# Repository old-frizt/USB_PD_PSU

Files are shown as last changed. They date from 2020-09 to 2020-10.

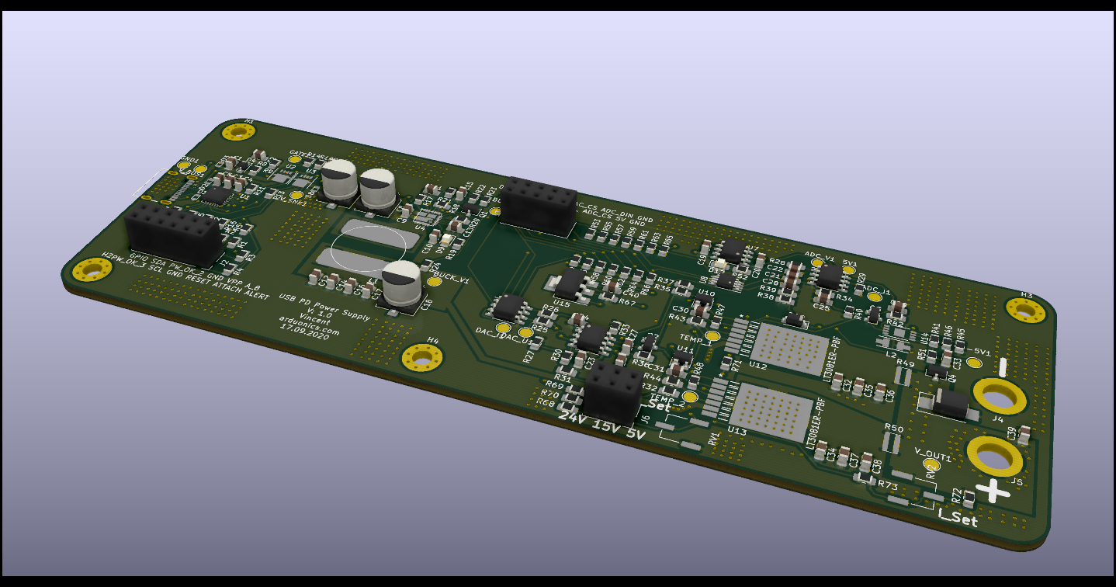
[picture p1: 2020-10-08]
USB_PD_PSU_render.png

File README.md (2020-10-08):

# USB_PD_PSU
DIY USB Power Delivery Lab Bench Power Supply

WORK-IN-PROGRESS

This is a power supply with a linear ouput stage and a switching pre regulator.
In the future it will be controlled via a microcontroller doughter board.

The power to the supply is comes from USB Power-delivery at 20V.
The ouput can be set between 0-20V and 0-3A.

Additional information can be found on my website: https://arduonics.com/2020/electronics/diy-usb-power-delivery-lab-bench-power-supply/

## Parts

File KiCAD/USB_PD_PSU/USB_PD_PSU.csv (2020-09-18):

Source: | E:\DOKUMENTE\KiCAD\PSU\psu\USB_PD_PSU\USB_PD_PSU.sch
Date: | 15.09.2020 12:40:33
Tool: | Eeschema (5.1.6)-1
Generator: | C:\Program Files\KiCad\bin\scripting\plugins/bom_csv_grouped_by_value_with_fp_DigiKey.py
Component Count: | 132
Ref | Qnty | Value | Cmp name | Footprint | DigiKey
C1, | 1 | C CER 4.7uF 20V X5R | C | Capacitor_SMD:C_0805_2012Metric_Pad1.15x1.40mm_HandSolder
C2, C3, C4, C5, C13, C24, C30, C31, C39, | 9 | 1uF | C | Capacitor_SMD:C_0805_2012Metric_Pad1.15x1.40mm_HandSolder
C6, C9, C19, C20, C21, C22, C25, | 7 | 100nF | C | Capacitor_SMD:C_0805_2012Metric_Pad1.15x1.40mm_HandSolder
C7, C8, | 2 | 22uF | C | Capacitor_SMD:C_0805_2012Metric_Pad1.15x1.40mm_HandSolder
C10, | 1 | 4u7F | C | Capacitor_SMD:C_0805_2012Metric_Pad1.15x1.40mm_HandSolder
C11, | 1 | 0.1uF | C | Capacitor_SMD:C_0805_2012Metric_Pad1.15x1.40mm_HandSolder
C12, C14, C16, C17, | 4 | 4u7 | C | Capacitor_SMD:C_0805_2012Metric_Pad1.15x1.40mm_HandSolder
C15, C23, C26, C27, | 4 | 1nF | C | Capacitor_SMD:C_0805_2012Metric_Pad1.15x1.40mm_HandSolder
C18, C28, | 2 | 100uF | C | Capacitor_SMD:C_0805_2012Metric_Pad1.15x1.40mm_HandSolder
C29, C32, C33, C34, C35, C36, C37, C38, | 8 | 10uF | C | Capacitor_SMD:C_0805_2012Metric_Pad1.15x1.40mm_HandSolder
D1, D2, D3, D8, | 4 | ESDA25P35 | D_Zener | Diode_SMD:QFN_1610_2-UDFN_ESDA25P35 | 497-16913-1-ND‎
D4, | 1 | D_Schottky | D_Schottky | Diode_SMD:D_SOD-323_HandSoldering | BAT54HT1GOSCT-ND
D5, D6, D7, D9, | 4 | LED | LED | LED_SMD:LED_0805_2012Metric_Pad1.15x1.40mm_HandSolder | 732-4987-1-ND
D10, | 1 | MBR0540 | MBR0540 | Diode_SMD:D_SOD-123 | MBR0540T3GOSCT-ND
D11, | 1 | SM6T36A | D | Diode_SMD:D_SMB_Handsoldering | ‎497-6495-1-ND‎
J1, | 1 | USB_C_Receptacle_UJ31-CH-3-SMT-TR | USB_C_Receptacle_UJ31-CH-3-SMT-TR | Connector_USB:CUI_UJ31-CH-3-SMT-TR | 102-4484-1-ND
J2, | 1 | Conn_02x06_Counter_Clockwise | Conn_02x06_Counter_Clockwise | Connector_PinSocket_2.54mm:PinSocket_2x06_P2.54mm_Vertical
L1, | 1 | SDR1307-5R6ML | L | USB_PD_PSU:Inductor_SDR1307 | SDR1307-5R6MLCT-ND
L2, | 1 | 470u_LQH32CN471K23L | L | USB_PD_PSU:LQH32CN471K23L | 490-2499-1-ND
Q1, Q3, | 2 | MMBT3906 | MMBT3906 | Package_TO_SOT_SMD:SOT-23 | MMBT3906-FDICT-ND
Q2, | 1 | BC846BLT1G | BC847 | Package_TO_SOT_SMD:SOT-23 | BC846BLT1GOSCT-ND
Q4, | 1 | FMMT493TA | Q_NPN_BEC | Package_TO_SOT_SMD:SOT-23 | FMMT493CT-ND
R1, R6, R7, | 3 | 4k7 | R | Resistor_SMD:R_0805_2012Metric_Pad1.15x1.40mm_HandSolder
R2, R3, R4, R5, R10, R23, R24, | 7 | 100k | R | Resistor_SMD:R_0805_2012Metric_Pad1.15x1.40mm_HandSolder
R8, | 1 | 470 | R | Resistor_SMD:R_0805_2012Metric_Pad1.15x1.40mm_HandSolder
R9, R12, R13, R15, R16, R19, R22, R36, R40, | 9 | 1k | R | Resistor_SMD:R_0805_2012Metric_Pad1.15x1.40mm_HandSolder
R11, | 1 | 22k | R | Resistor_SMD:R_0805_2012Metric_Pad1.15x1.40mm_HandSolder
R14, R28, R29, | 3 | 100 | R | Resistor_SMD:R_0805_2012Metric_Pad1.15x1.40mm_HandSolder
R17, | 1 | 2.2 | R | Resistor_SMD:R_0805_2012Metric_Pad1.15x1.40mm_HandSolder
R18, | 1 | 51k | R | Resistor_SMD:R_0805_2012Metric_Pad1.15x1.40mm_HandSolder
R20, R35, R37, | 3 | 4k99 | R | Resistor_SMD:R_0805_2012Metric_Pad1.15x1.40mm_HandSolder
R21, | 1 | 499k | R | Resistor_SMD:R_0805_2012Metric_Pad1.15x1.40mm_HandSolder
R25, R26, | 2 | 33k2 | R | Resistor_SMD:R_0805_2012Metric_Pad1.15x1.40mm_HandSolder
R27, | 1 | 4k4 | R | Resistor_SMD:R_0805_2012Metric_Pad1.15x1.40mm_HandSolder
R30, | 1 | 11k | R | Resistor_SMD:R_0805_2012Metric_Pad1.15x1.40mm_HandSolder
R31, | 1 | 50k | R | Resistor_SMD:R_0805_2012Metric_Pad1.15x1.40mm_HandSolder
R32, | 1 | 10 | R | Resistor_SMD:R_0805_2012Metric_Pad1.15x1.40mm_HandSolder
R33, | 1 | 41k | R | Resistor_SMD:R_0805_2012Metric_Pad1.15x1.40mm_HandSolder
R34, | 1 | 5k | R | Resistor_SMD:R_0805_2012Metric_Pad1.15x1.40mm_HandSolder
R38, | 1 | 300k | R | Resistor_SMD:R_0805_2012Metric_Pad1.15x1.40mm_HandSolder
R39, | 1 | 99k | R | Resistor_SMD:R_0805_2012Metric_Pad1.15x1.40mm_HandSolder
R41, | 1 | 10k | R | Resistor_SMD:R_0805_2012Metric_Pad1.15x1.40mm_HandSolder
R42, | 1 | 806k | R | Resistor_SMD:R_0805_2012Metric_Pad1.15x1.40mm_HandSolder
R43, R44, R51, | 3 | 3k2 | R | Resistor_SMD:R_0805_2012Metric_Pad1.15x1.40mm_HandSolder
R45, | 1 | 1M47 | R | Resistor_SMD:R_0805_2012Metric_Pad1.15x1.40mm_HandSolder
R46, | 1 | 280k | R | Resistor_SMD:R_0805_2012Metric_Pad1.15x1.40mm_HandSolder
R47, R48, | 2 | 402 | R | Resistor_SMD:R_0805_2012Metric_Pad1.15x1.40mm_HandSolder
R49, R50, | 2 | 0.1/1W | R | Resistor_SMD:CFG0612 | LTC3632EMS8E#PBF-ND‎
TP1, | 1 | GND | TestPoint | TestPoint:TestPoint_Pad_D2.0mm
TP2, | 1 | CC1 | TestPoint | TestPoint:TestPoint_Pad_D2.0mm
TP3, | 1 | CC2 | TestPoint | TestPoint:TestPoint_Pad_D2.0mm
TP4, | 1 | VBUS | TestPoint | TestPoint:TestPoint_Pad_D2.0mm
TP5, TP6, | 2 | 2V7 | TestPoint | TestPoint:TestPoint_Pad_D2.0mm
TP7, | 1 | VDD | TestPoint | TestPoint:TestPoint_Pad_D2.0mm
TP8, | 1 | GATE | TestPoint | TestPoint:TestPoint_Pad_D2.0mm
TP9, | 1 | VSNK | TestPoint | TestPoint:TestPoint_Pad_D2.0mm
U1, | 1 | STUSB4500QTR | STUSB4500QTR | Package_DFN_QFN:QFN-24-1EP_4x4mm_P0.5mm_EP2.7x2.7mm | 497-18060-1-ND
U2, U3, | 2 | STL6P3LLH6 | STL6P3LLH6 | Package_DFN_QFN:8-PowerVDFN | 497-15315-1-ND
U4, | 1 | SIC438AED | SIC438AED | USB_PD_PSU:MLP44-24L PowerPAK | SIC438AED-T1-GE3CT-ND
U5, | 1 | MCP4822 | MCP4822 | Package_SO:SOIC-8_3.9x4.9mm_P1.27mm | MCP4822-E/SN-ND‎
U6, | 1 | MCP6422T-E/SN | Opamp_Dual_Generic | Package_SO:SOIC-8_3.9x4.9mm_P1.27mm | MCP6422T-E/SNCT-ND
U7, | 1 | L78L05_SO8 | L78L05_SO8 | Package_SO:SOIC-8_3.9x4.9mm_P1.27mm | ‎497-7267-1-ND‎
U8, | 1 | MCP3202 | MCP3202 | Package_SO:MSOP-8_3x3mm_P0.65mm | MCP3202T-CI/MSCT-ND
U9, | 1 | LT1013DDR | LT1013DDR | Package_SO:SOIC-8_3.9x4.9mm_P1.27mm | 296-14615-1-ND‎
U10, U11, | 2 | BCV62CE6327HTSA1 | BCV62CE6327HTSA1 | Package_TO_SOT_SMD:SOT-143 | ‎BCV62CE6327HTSA1CT-ND‎
U12, U13, | 2 | LT3081ER-PBF | LT3081ER-PBF | Package_DD:LT3081ER_7-DDPAK | ‎LT3081ER#PBF-ND‎
U14, | 1 | LTC3632 | LTC3632 | Package_SO:MSOP_MS8E | LTC3632EMS8E#PBF-ND‎

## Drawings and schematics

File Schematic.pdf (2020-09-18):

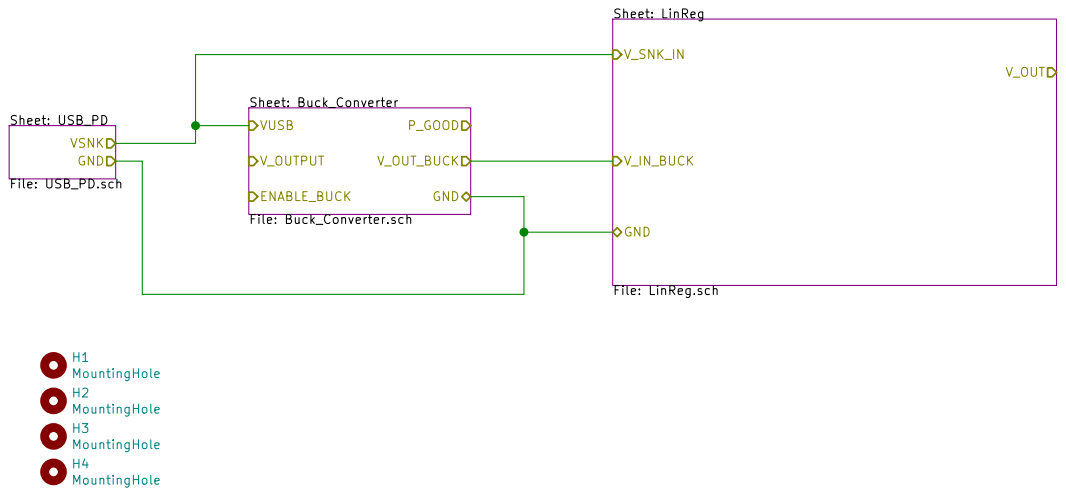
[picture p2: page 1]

Sheet: Buck_Converter File: Buck_Converter.sch VUSB

Sheet: USB_PD
File: USB_PD.sch VSNK GND

File: USB_PD_PSU.sch Sheet: / arduonics.com

Id: 1/4 Title: USB PD PSU

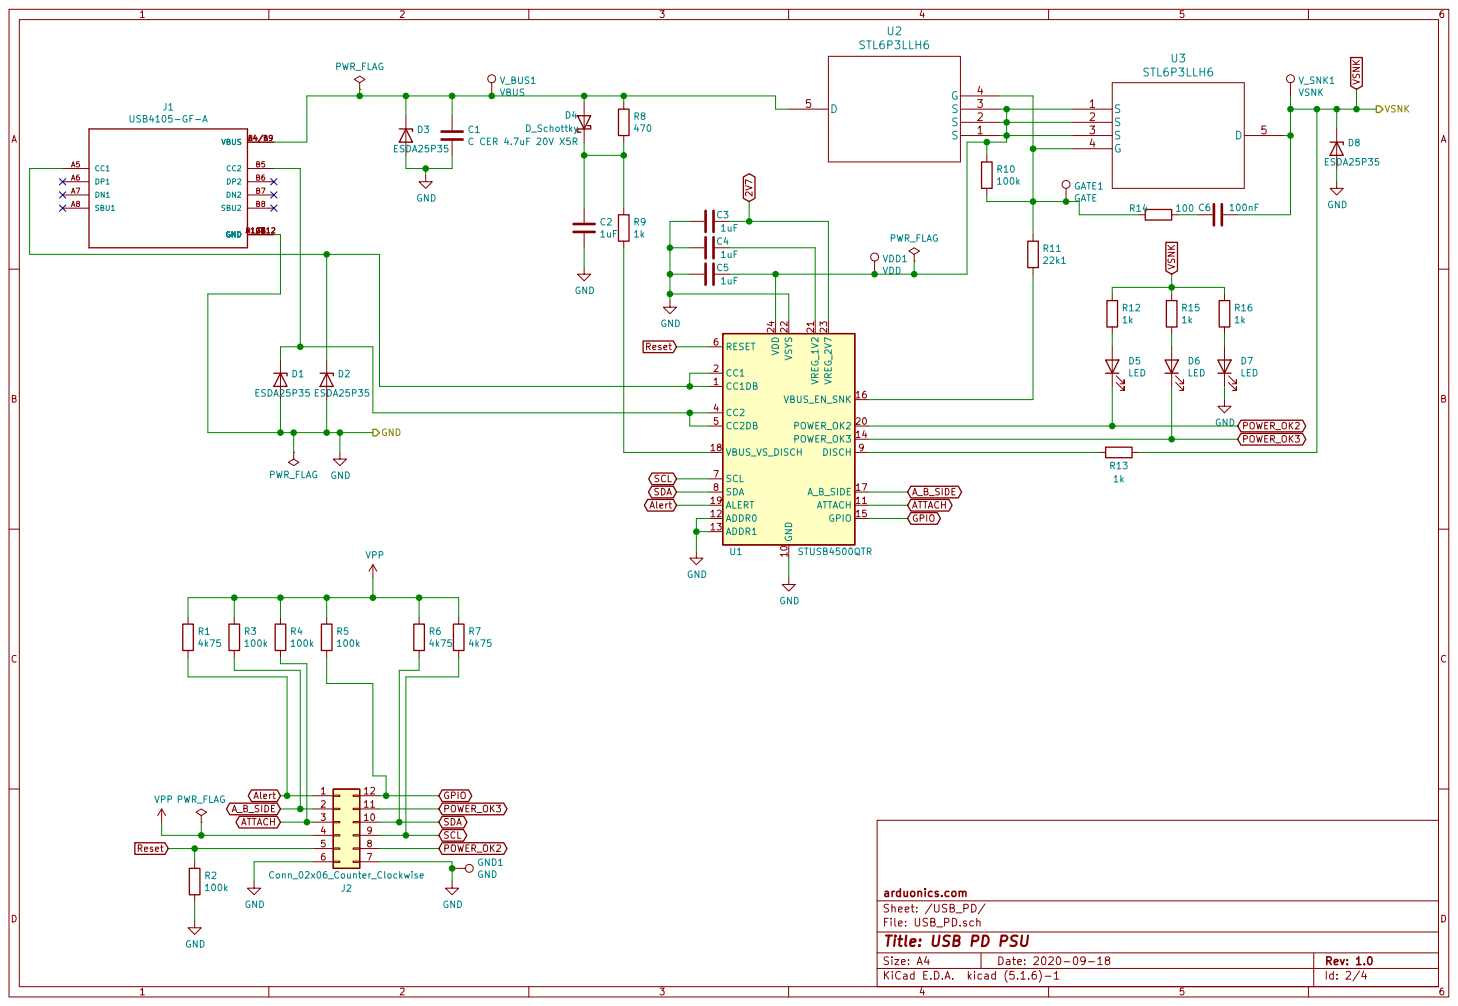
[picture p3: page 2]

File: USB_PD.sch
Id: 2/4 Title: USB PD PSU

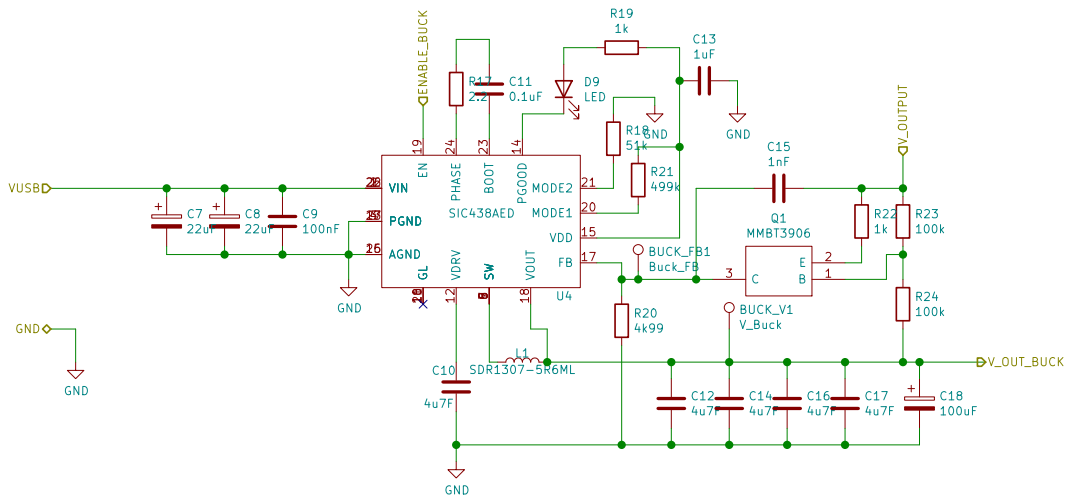
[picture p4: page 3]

File: Buck_Converter.sch
Id: 3/4 Title: USB PD PSU

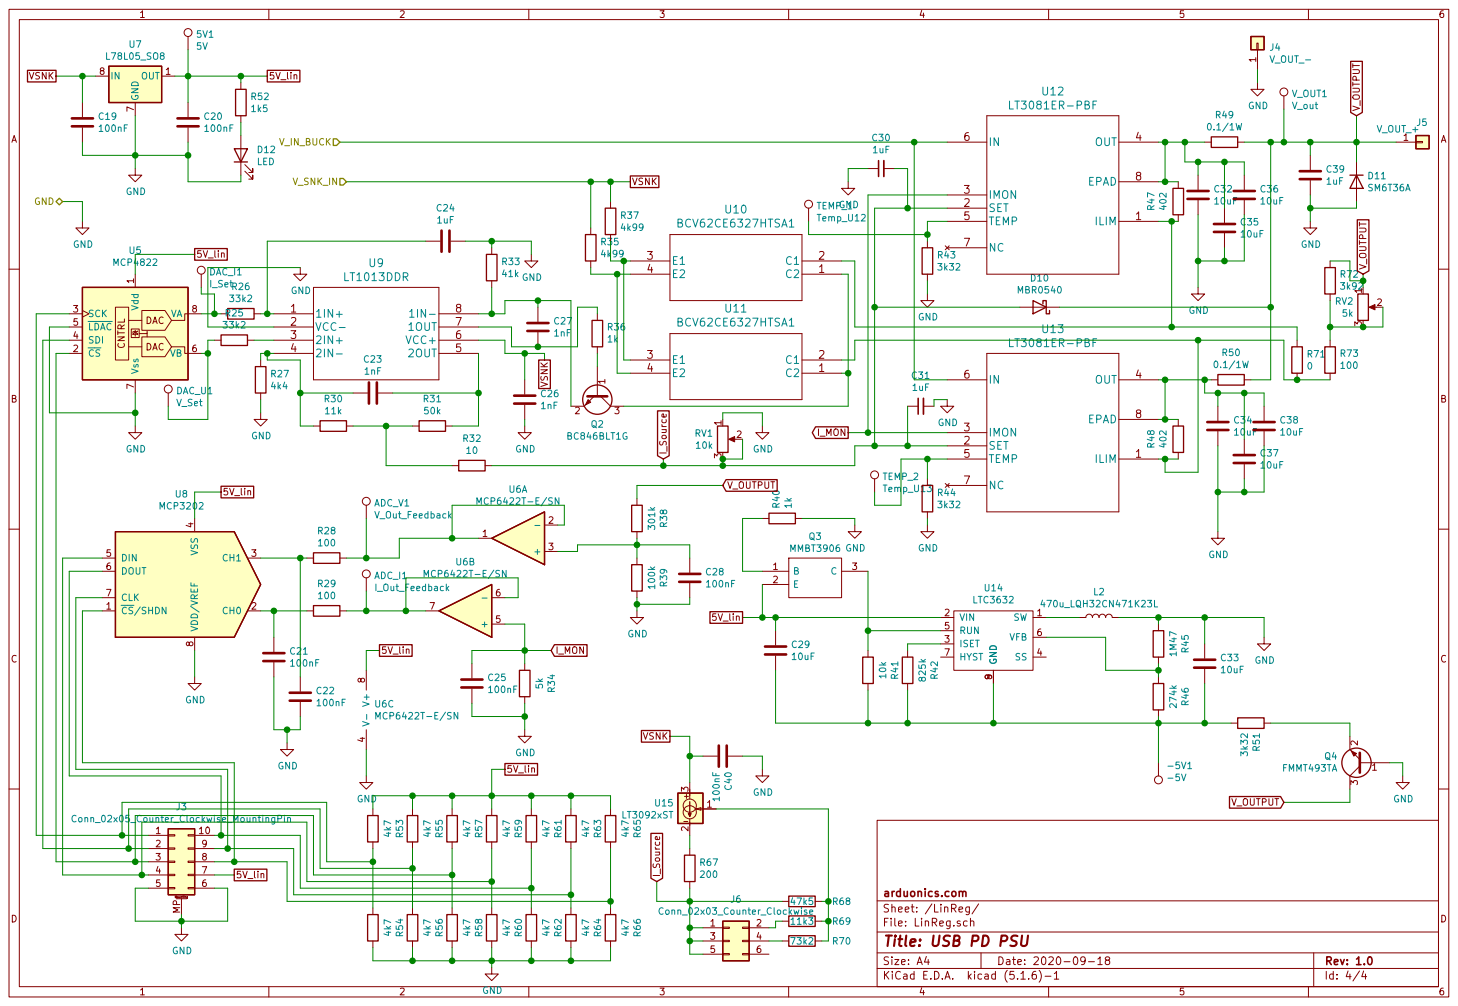
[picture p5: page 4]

4 DIN 5 DOUT 6 CLK 7 VDD/VREF

Sheet: /LinReg/ arduonics.com

File: LinReg.sch
Id: 4/4 Title: USB PD PSU

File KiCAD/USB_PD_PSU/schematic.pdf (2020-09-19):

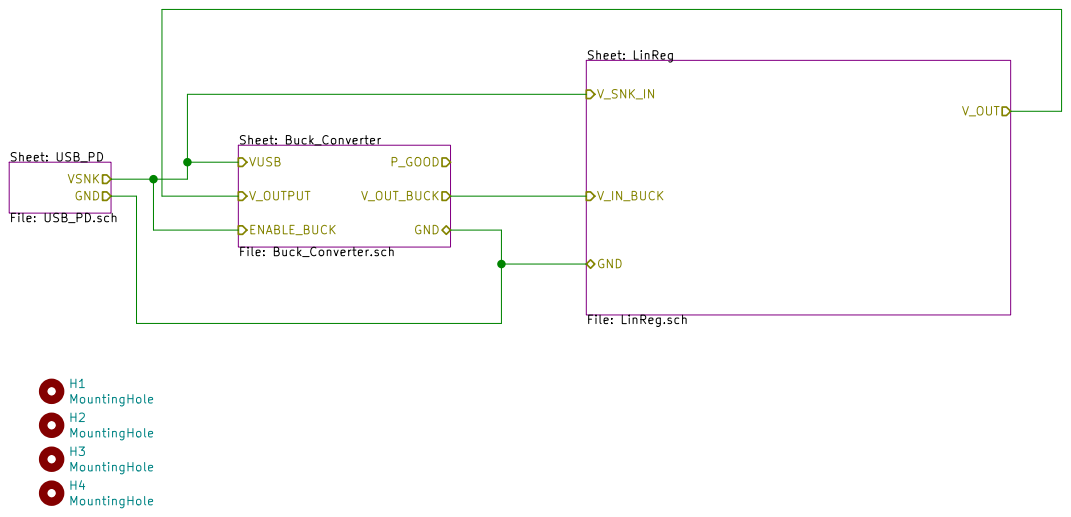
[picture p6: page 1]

Sheet: Buck_Converter File: Buck_Converter.sch VUSB

Sheet: USB_PD
File: USB_PD.sch VSNK GND

File: LinReg.sch GND

File: USB_PD_PSU.sch Sheet: / arduonics.com

Id: 1/4 Title: USB PD PSU


File: USB_PD.sch
Id: 2/4 Title: USB PD PSU

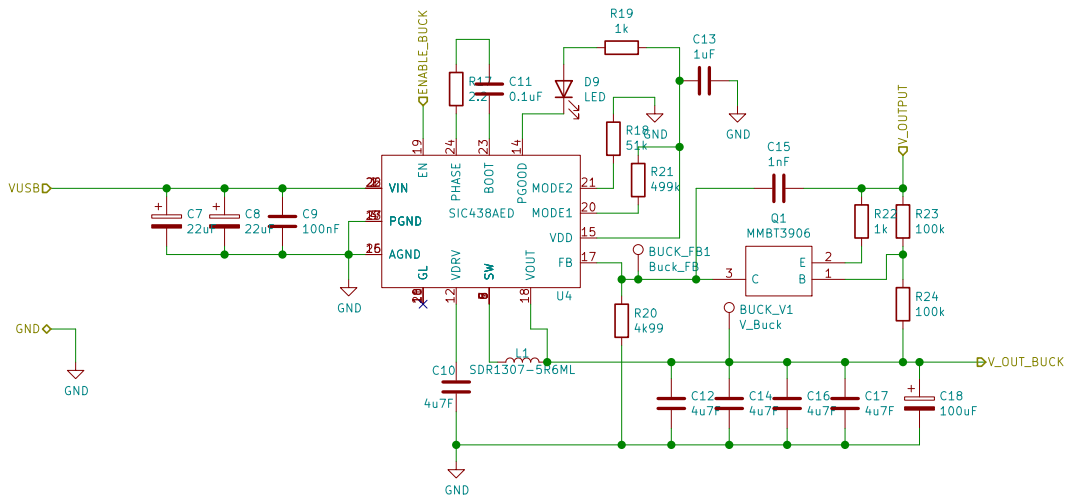
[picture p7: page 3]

File: Buck_Converter.sch
Id: 3/4 Title: USB PD PSU

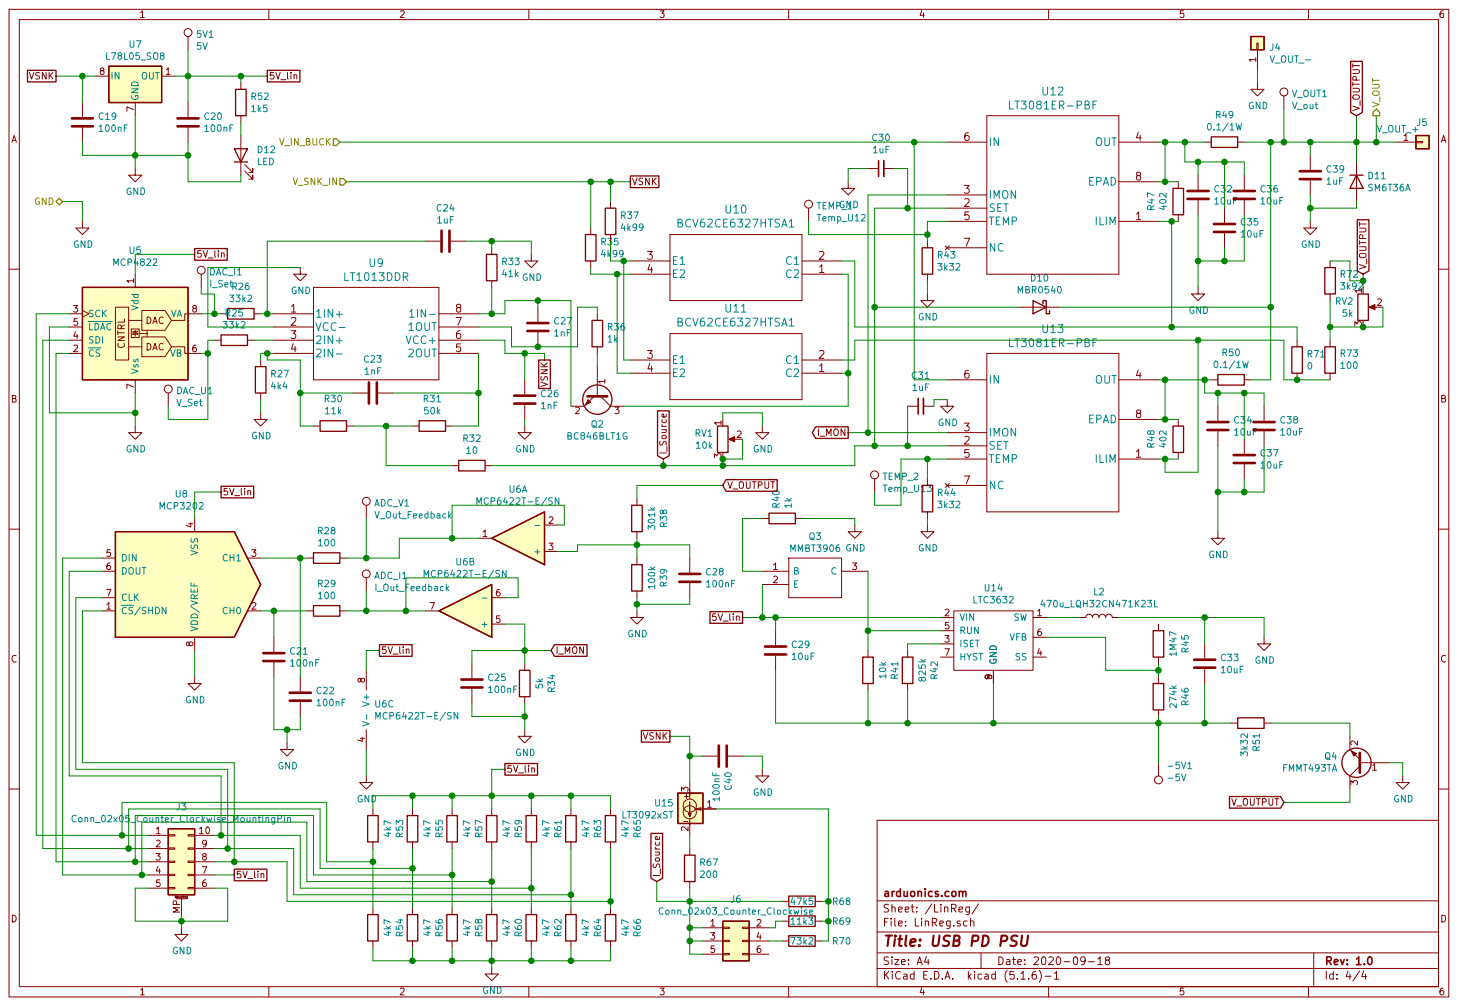
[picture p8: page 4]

4 DIN 5 DOUT 6 CLK 7 VDD/VREF

File: LinReg.sch
Id: 4/4 Title: USB PD PSU

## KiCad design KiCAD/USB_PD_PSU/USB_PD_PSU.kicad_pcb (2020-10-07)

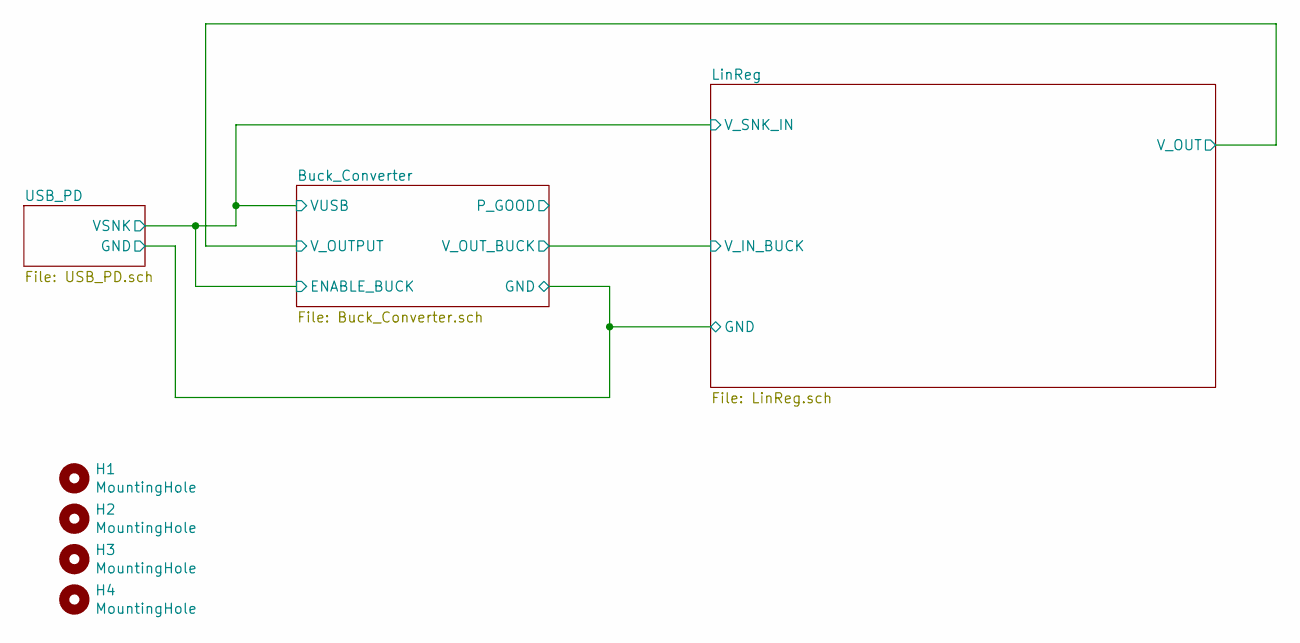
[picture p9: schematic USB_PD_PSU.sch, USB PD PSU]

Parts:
H1, H2, H3, H4: MountingHole; MountingHole_3.2mm_M3_Pad_Via

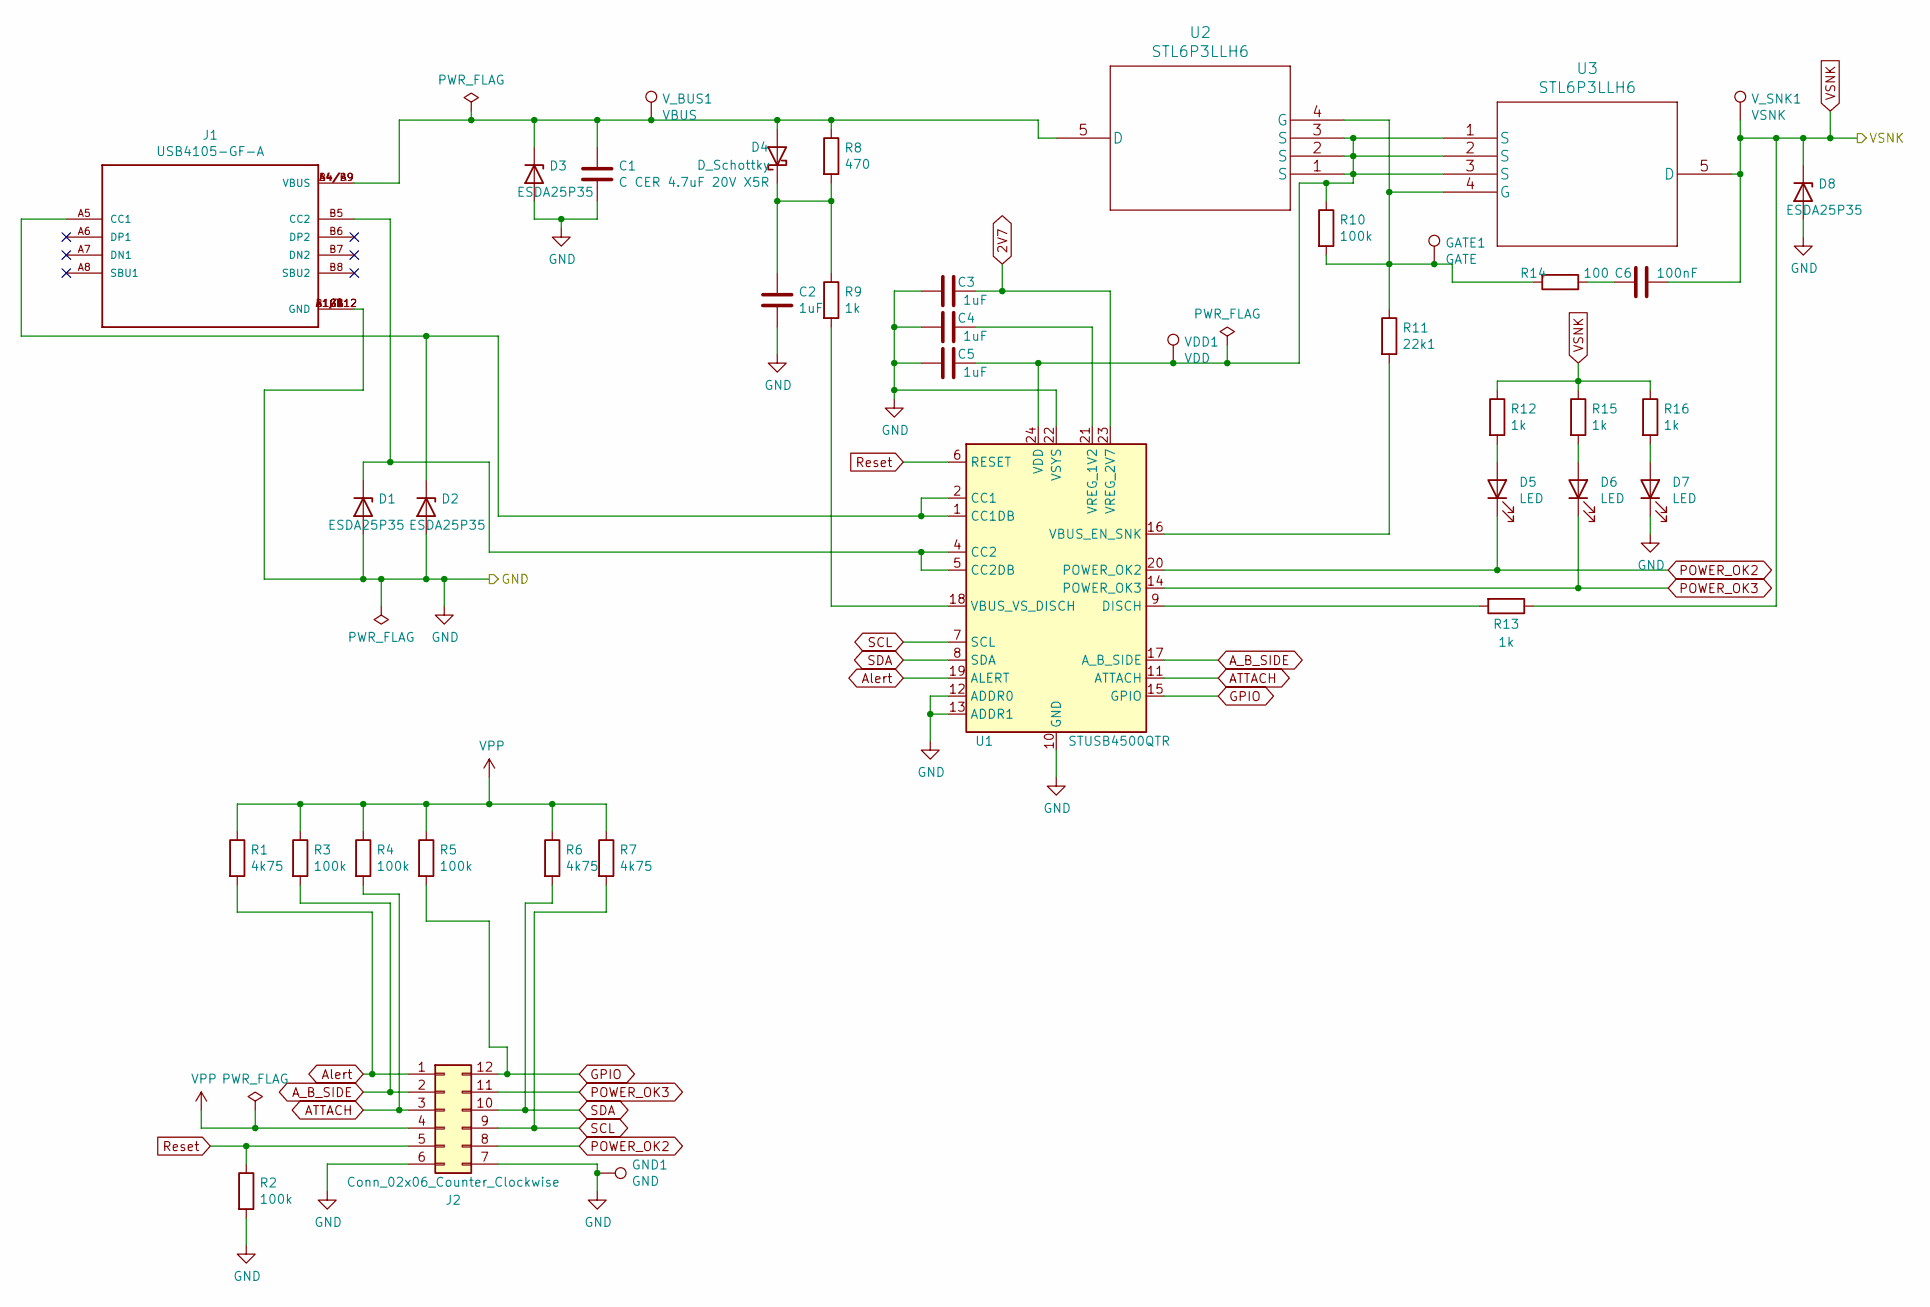
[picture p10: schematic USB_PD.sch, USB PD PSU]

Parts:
C1: C CER 4.7uF 20V X5R; C_0805_2012Metric_Pad1.15x1.40mm_HandSolder
C2, C3, C4, C5: 1uF; C_0805_2012Metric_Pad1.15x1.40mm_HandSolder
C6: 100nF; C_0805_2012Metric_Pad1.15x1.40mm_HandSolder
D1, D2, D3, D8: ESDA25P35; QFN_1610_2-UDFN_ESDA25P35; DigiKey 497-16913-1-ND‎
D4: D_Schottky; D_SOD-323_HandSoldering; DigiKey BAT54HT1GOSCT-ND
D5, D6, D7: LED; LED_0805_2012Metric_Pad1.15x1.40mm_HandSolder; DigiKey 732-4987-1-ND
GATE1: GATE; TestPoint_Pad_D2.0mm
GND1: GND; TestPoint_Pad_D2.0mm
J1: USB4105-GF-A; USB_C_Rec_USB4105-GF-A
J2: Conn_02x06_Counter_Clockwise; PinSocket_2x06_P2.54mm_Vertical
R1, R6, R7: 4k75; R_0805_2012Metric_Pad1.15x1.40mm_HandSolder
R2, R3, R4, R5, R10: 100k; R_0805_2012Metric_Pad1.15x1.40mm_HandSolder
R8: 470; R_0805_2012Metric_Pad1.15x1.40mm_HandSolder
R9, R12, R13, R15, R16: 1k; R_0805_2012Metric_Pad1.15x1.40mm_HandSolder
R11: 22k1; R_0805_2012Metric_Pad1.15x1.40mm_HandSolder
R14: 100; R_0805_2012Metric_Pad1.15x1.40mm_HandSolder
U1: STUSB4500QTR; QFN-24-1EP_4x4mm_P0.5mm_EP2.7x2.7mm; DigiKey 497-18060-1-ND
U2, U3: STL6P3LLH6; PowerFLAT_3.3x3.3; DigiKey 497-15315-1-ND
VDD1: VDD; TestPoint_Pad_D2.0mm
V_BUS1: VBUS; TestPoint_Pad_D2.0mm
V_SNK1: VSNK; TestPoint_Pad_D2.0mm

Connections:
2V7: C3.1, U1.23 (VREG_2V7)
ATTACH: J2.3, R4.2, U1.11 (ATTACH)
A_B_SIDE: J2.2, R3.2, U1.17 (A_B_SIDE)
Alert: J2.1, R1.2, U1.19 (ALERT)
GND: C1.2, C2.2, C3.2, C4.2, C5.2, D1.2 (A), D2.2 (A), D3.2 (A), D7.1 (K), D8.2 (A), GND1.1, J1.A1/B12 (GND), J1.B1/A12 (GND), J1.G1 (GND), J1.G2 (GND), J1.G3 (GND), J1.G4 (GND), J2.6, J2.7, R2.2, U1.10 (GND), U1.12 (ADDR0), U1.13 (ADDR1), U1.22 (VSYS), U1.25 (GND); also elsewhere on the board
GPIO: J2.12, R5.2, U1.15 (GPIO)
unnamed: C1.1, D3.1 (K), D4.2 (A), J1.A4/B9 (VBUS), J1.B4/A9 (VBUS), R8.1, U2.5 (D), V_BUS1.1
unnamed: C2.1, D4.1 (K), R8.2, R9.1
unnamed: C4.1, U1.21 (VREG_1V2)
unnamed: C5.1, R10.1, U1.24 (VDD), U2.1 (S), U2.2 (S), U2.3 (S), U3.1 (S), U3.2 (S), U3.3 (S), VDD1.1
unnamed: C6.1, R14.1
unnamed: D1.1 (K), J1.B5 (CC2), U1.4 (CC2), U1.5 (CC2DB)
unnamed: D2.1 (K), J1.A5 (CC1), U1.1 (CC1DB), U1.2 (CC1)
unnamed: D5.2 (A), R12.2
unnamed: D6.2 (A), R15.2
unnamed: D7.2 (A), R16.2
unnamed: GATE1.1, R10.2, R11.1, R14.2, U2.4 (G), U3.4 (G)
unnamed: R9.2, U1.18 (VBUS_VS_DISCH)
unnamed: R11.2, U1.16 (VBUS_EN_SNK)
unnamed: R13.2, U1.9 (DISCH)
POWER_OK2: D5.1 (K), J2.8, U1.20 (POWER_OK2)
POWER_OK3: D6.1 (K), J2.11, U1.14 (POWER_OK3)
Reset: J2.5, R2.1, U1.6 (RESET)
SCL: J2.9, R7.2, U1.7 (SCL)
SDA: J2.10, R6.2, U1.8 (SDA)
VPP: J2.4, R1.1, R3.1, R4.1, R5.1, R6.1, R7.1
VSNK: C6.2, D8.1 (K), R12.1, R13.1, R15.1, R16.1, U3.5 (D), V_SNK1.1; also elsewhere on the board

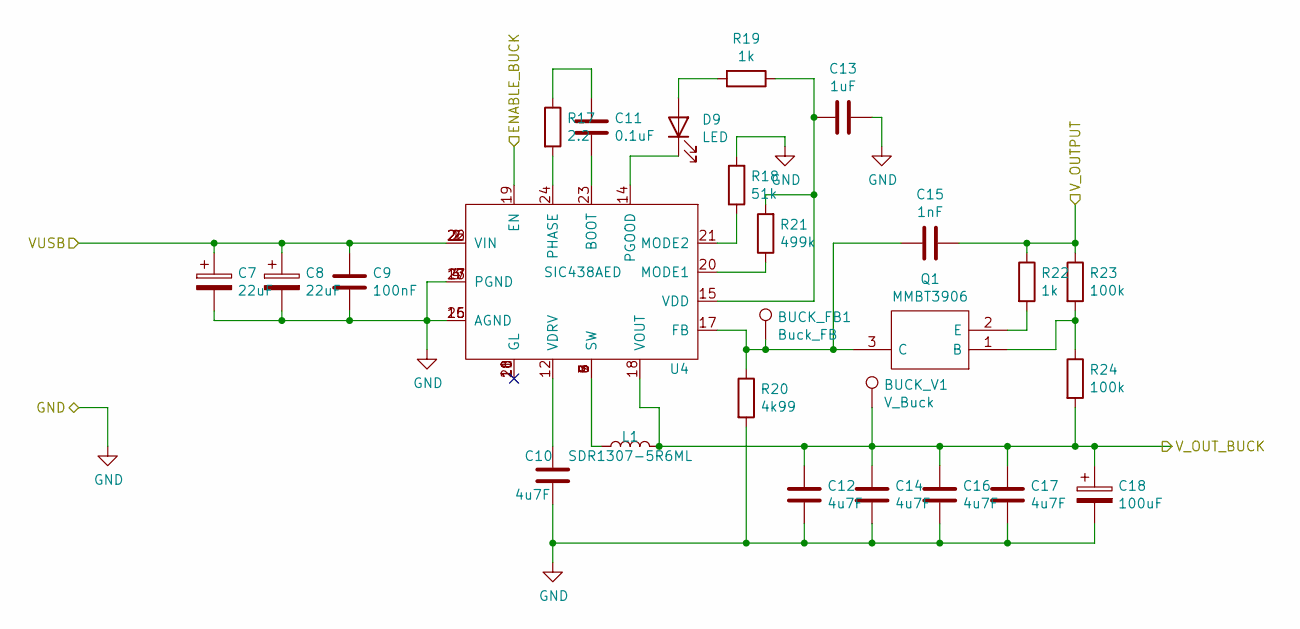
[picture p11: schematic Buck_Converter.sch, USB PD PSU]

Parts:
BUCK_FB1: Buck_FB; TestPoint_Pad_D2.0mm
BUCK_V1: V_Buck; TestPoint_Pad_D2.0mm
C7, C8: 22uF; CP_Elec_6.3x5.9; DigiKey 732-8453-1-ND
C9: 100nF; C_0805_2012Metric_Pad1.15x1.40mm_HandSolder
C10, C12, C14, C16, C17: 4u7F; C_0805_2012Metric_Pad1.15x1.40mm_HandSolder
C11: 0.1uF; C_0805_2012Metric_Pad1.15x1.40mm_HandSolder
C13: 1uF; C_0805_2012Metric_Pad1.15x1.40mm_HandSolder
C15: 1nF; C_0805_2012Metric_Pad1.15x1.40mm_HandSolder
C18: 100uF; CP_Elec_6.3x5.9; DigiKey 732-8511-1-ND
D9: LED; LED_0805_2012Metric_Pad1.15x1.40mm_HandSolder; DigiKey 732-4987-1-ND
L1: SDR1307-5R6ML; Inductor_SDR1307; DigiKey SDR1307-5R6MLCT-ND
Q1: MMBT3906; SOT-23; Mouser Part Number 512-MMBT3906
R17: 2.2; R_0805_2012Metric_Pad1.15x1.40mm_HandSolder; DigiKey RL12S2.20FCT-ND
R18: 51k; R_0805_2012Metric_Pad1.15x1.40mm_HandSolder
R19, R22: 1k; R_0805_2012Metric_Pad1.15x1.40mm_HandSolder
R20: 4k99; R_0805_2012Metric_Pad1.15x1.40mm_HandSolder
R21: 499k; R_0805_2012Metric_Pad1.15x1.40mm_HandSolder
R23, R24: 100k; R_0805_2012Metric_Pad1.15x1.40mm_HandSolder
U4: SIC438AED; MLP44-24L PowerPAK; DigiKey SIC438AED-T1-GE3CT-ND

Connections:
/LinReg/V_IN_BUCK: BUCK_V1.1, C12.1, C14.1, C16.1, C17.1, C18.1, L1.2, R24.2, U4.18 (VOUT); also elsewhere on the board
GND: C7.2, C8.2, C9.2, C10.2, C12.2, C13.1, C14.2, C16.2, C17.2, C18.2, R18.2, R20.2, U4.3 (PGND), U4.4 (PGND), U4.13 (PGND), U4.16 (AGND), U4.25 (AGND), U4.27 (PGND); also elsewhere on the board
unnamed: BUCK_FB1.1, C15.2, Q1.3 (C), R20.1, U4.17 (FB)
unnamed: C10.1, U4.12 (VDRV)
unnamed: C11.1, R17.1
unnamed: C11.2, U4.23 (BOOT)
unnamed: C13.2, R19.1, R21.2, U4.15 (VDD)
unnamed: D9.1 (K), U4.14 (PGOOD)
unnamed: D9.2 (A), R19.2
unnamed: L1.1, U4.5 (SW), U4.6 (SW), U4.7 (SW), U4.8 (SW), U4.9 (SW)
unnamed: Q1.1 (B), R23.2, R24.1
unnamed: Q1.2 (E), R22.2
unnamed: R17.2, U4.24 (PHASE)
unnamed: R18.1, U4.21 (MODE2)
unnamed: R21.1, U4.20 (MODE1)
unnamed: U4.10 (GL), U4.11 (GL), U4.28 (GL)
VSNK: C7.1, C8.1, C9.1, U4.1 (VIN), U4.2 (VIN), U4.19 (EN), U4.22 (VIN), U4.26 (VIN); also elsewhere on the board
V_OUTPUT: C15.1, R22.1, R23.1; also elsewhere on the board

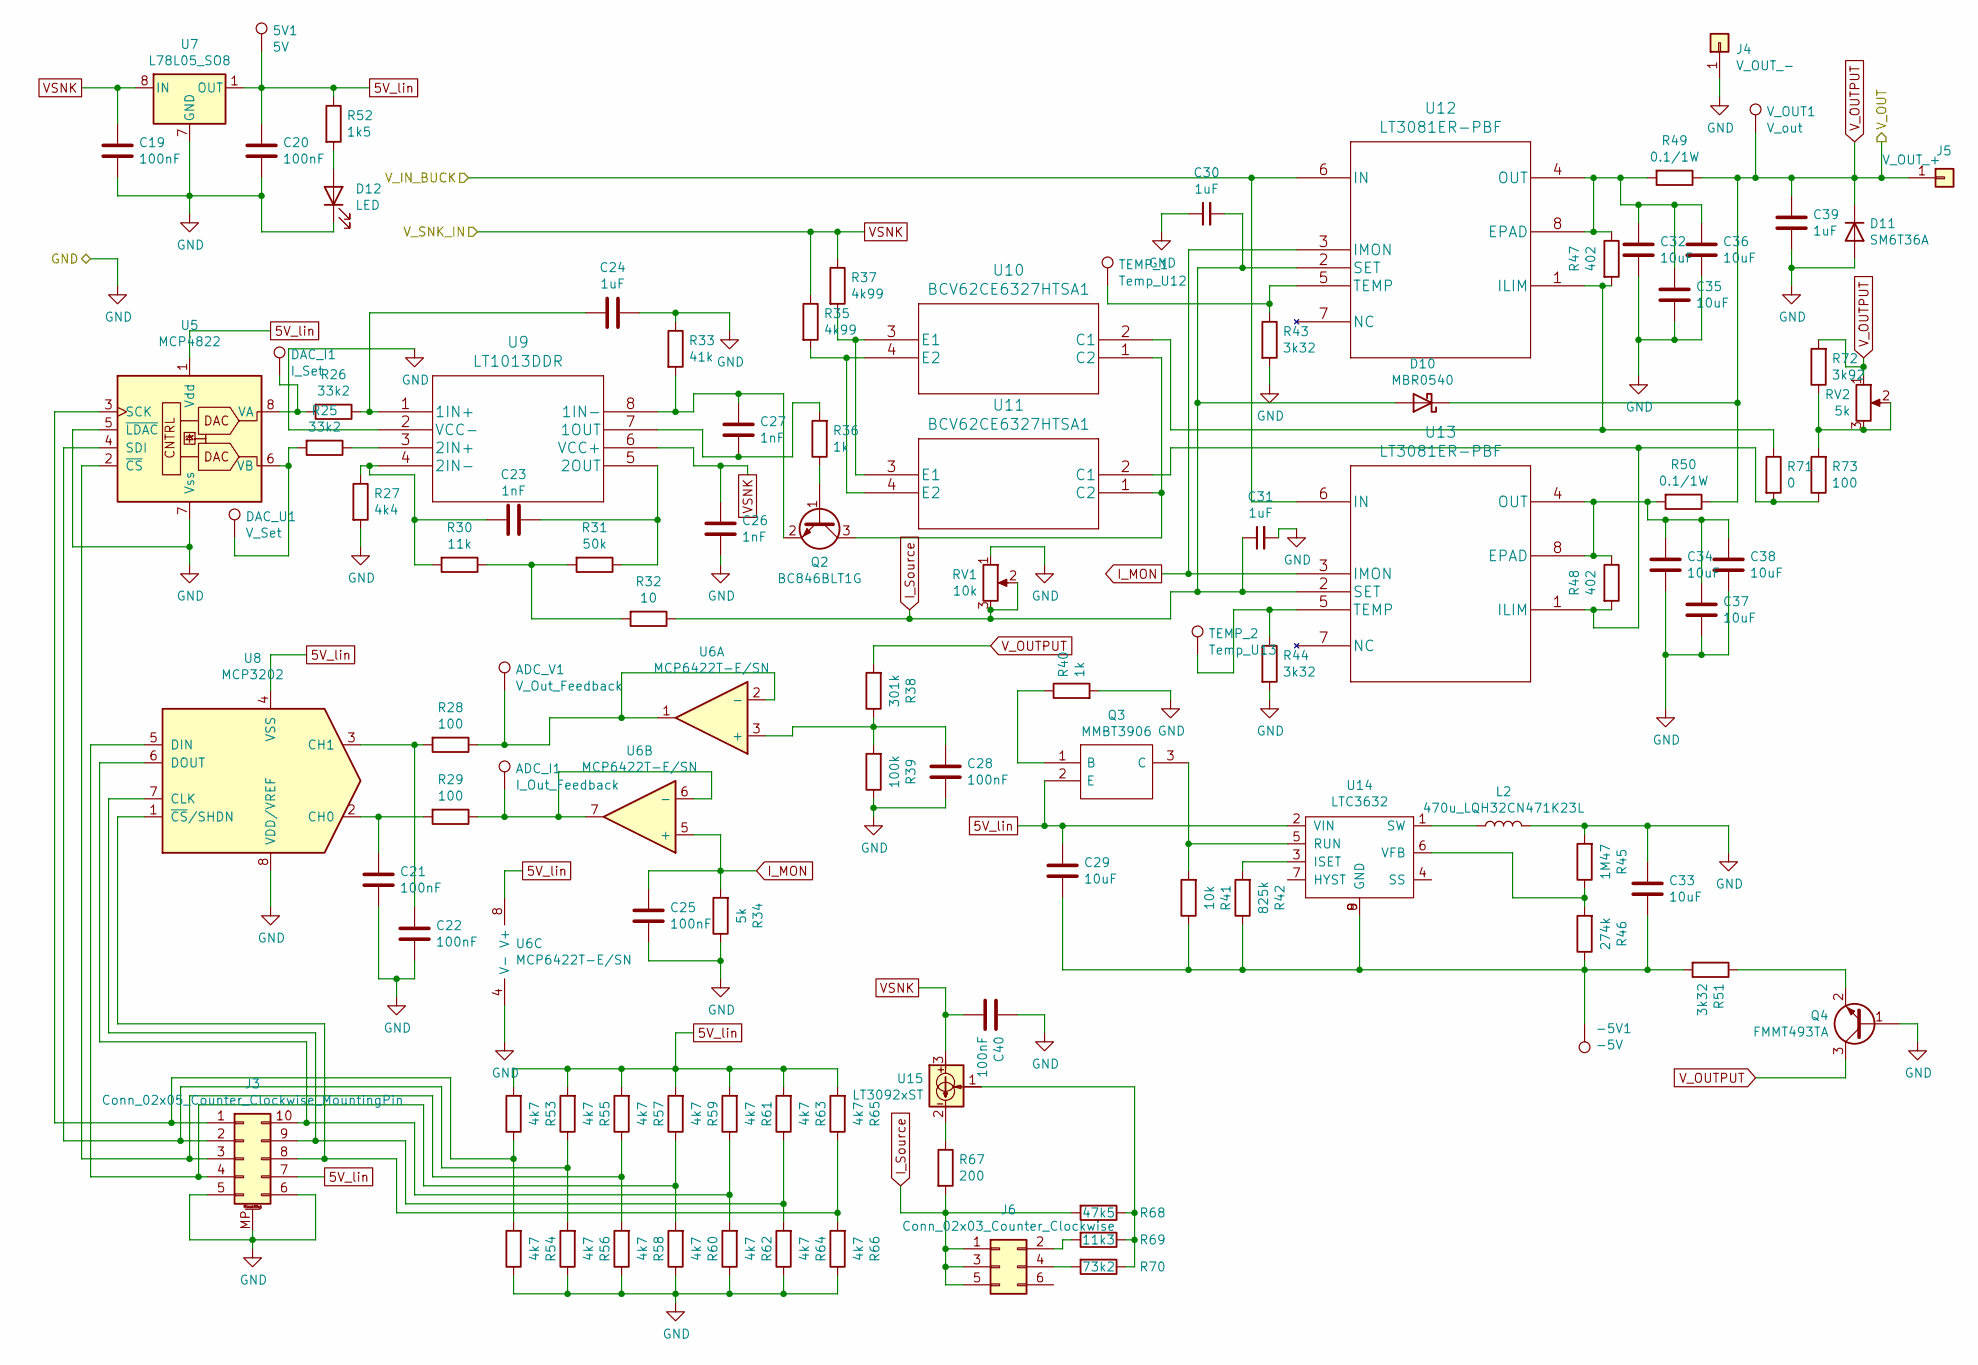
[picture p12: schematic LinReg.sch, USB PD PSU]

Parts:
5V1: 5V; TestPoint_Pad_D2.0mm
-5V1: -5V; TestPoint_Pad_D2.0mm
ADC_I1: I_Out_Feedback; TestPoint_Pad_D2.0mm
ADC_V1: V_Out_Feedback; TestPoint_Pad_D2.0mm
C19, C20, C21, C22, C25, C28, C40: 100nF; C_0805_2012Metric_Pad1.15x1.40mm_HandSolder
C23, C26, C27: 1nF; C_0805_2012Metric_Pad1.15x1.40mm_HandSolder
C24, C30, C31, C39: 1uF; C_0805_2012Metric_Pad1.15x1.40mm_HandSolder
C29, C32, C33, C34, C35, C36, C37, C38: 10uF; C_0805_2012Metric_Pad1.15x1.40mm_HandSolder
D10: MBR0540; D_SOD-123; DigiKey MBR0540T3GOSCT-ND
D11: SM6T36A; D_SMB_Handsoldering; DigiKey ‎497-6495-1-ND‎
D12: LED; LED_0805_2012Metric_Pad1.15x1.40mm_HandSolder
DAC_I1: I_Set; TestPoint_Pad_D2.0mm
DAC_U1: V_Set; TestPoint_Pad_D2.0mm
J3: Conn_02x05_Counter_Clockwise_MountingPin; PinSocket_2x05_P2.54mm_Vertical
J4: V_OUT_-; Banana_575-4
J5: V_OUT_+; Banana_575-4
J6: Conn_02x03_Counter_Clockwise; PinSocket_2x03_P2.54mm_Vertical
L2: 470u_LQH32CN471K23L; LQH32CN471K23L; DigiKey 490-2499-1-ND
Q2: BC846BLT1G; SOT-23; DigiKey BC846BLT1GOSCT-ND
Q3: MMBT3906; SOT-23; Mouser Part Number 512-MMBT3906
Q4: FMMT493TA; SOT-23; DigiKey FMMT493CT-ND
R25, R26: 33k2; R_0805_2012Metric_Pad1.15x1.40mm_HandSolder
R27: 4k4; R_0805_2012Metric_Pad1.15x1.40mm_HandSolder
R28, R29, R73: 100; R_0805_2012Metric_Pad1.15x1.40mm_HandSolder
R30: 11k; R_0805_2012Metric_Pad1.15x1.40mm_HandSolder
R31: 50k; R_0805_2012Metric_Pad1.15x1.40mm_HandSolder
R32: 10; R_0805_2012Metric_Pad1.15x1.40mm_HandSolder
R33: 41k; R_0805_2012Metric_Pad1.15x1.40mm_HandSolder
R34: 5k; R_0805_2012Metric_Pad1.15x1.40mm_HandSolder
R35, R37: 4k99; R_0805_2012Metric_Pad1.15x1.40mm_HandSolder
R36, R40: 1k; R_0805_2012Metric_Pad1.15x1.40mm_HandSolder
R38: 301k; R_0805_2012Metric_Pad1.15x1.40mm_HandSolder
R39: 100k; R_0805_2012Metric_Pad1.15x1.40mm_HandSolder
R41: 10k; R_0805_2012Metric_Pad1.15x1.40mm_HandSolder
R42: 825k; R_0805_2012Metric_Pad1.15x1.40mm_HandSolder
R43, R44, R51: 3k32; R_0805_2012Metric_Pad1.15x1.40mm_HandSolder
R45: 1M47; R_0805_2012Metric_Pad1.15x1.40mm_HandSolder
R46: 274k; R_0805_2012Metric_Pad1.15x1.40mm_HandSolder
R47, R48: 402; R_0805_2012Metric_Pad1.15x1.40mm_HandSolder
R49, R50: 0.1/1W; CFG0612; DigiKey LTC3632EMS8E#PBF-ND‎
R52: 1k5; R_0805_2012Metric_Pad1.15x1.40mm_HandSolder
R53, R54, R55, R56, R57, R58, R59, R60, R61, R62, R63, R64, R65, R66: 4k7; R_0805_2012Metric_Pad1.15x1.40mm_HandSolder
R67: 200; R_0805_2012Metric_Pad1.15x1.40mm_HandSolder
R68: 47k5; R_0805_2012Metric_Pad1.15x1.40mm_HandSolder
R69: 11k3; R_0805_2012Metric_Pad1.15x1.40mm_HandSolder
R70: 73k2; R_0805_2012Metric_Pad1.15x1.40mm_HandSolder
R71: 0; R_0805_2012Metric_Pad1.15x1.40mm_HandSolder
R72: 3k92; R_0805_2012Metric_Pad1.15x1.40mm_HandSolder
RV1: 10k; 84W_Trimmer; DigiKey 987-1806-1-ND‎
RV2: 5k; 84W_Trimmer; DigiKey ‎987-1810-1-ND‎
TEMP_1: Temp_U12; TestPoint_Pad_D2.0mm
TEMP_2: Temp_U13; TestPoint_Pad_D2.0mm
U5: MCP4822; SOIC-8_3.9x4.9mm_P1.27mm; DigiKey MCP4822-E/SN-ND‎
U6: MCP6422T-E/SN; SOIC-8_3.9x4.9mm_P1.27mm; DigiKey MCP6422T-E/SNCT-ND
U7: L78L05_SO8; SOIC-8_3.9x4.9mm_P1.27mm; DigiKey ‎497-7267-1-ND‎
U8: MCP3202; MSOP-8_3x3mm_P0.65mm; DigiKey MCP3202T-CI/MSCT-ND
U9: LT1013DDR; SOIC-8_3.9x4.9mm_P1.27mm; DigiKey 296-14615-1-ND‎
U10, U11: BCV62CE6327HTSA1; SOT-143; DigiKey ‎BCV62CE6327HTSA1CT-ND‎
U12, U13: LT3081ER-PBF; LT3081ER_7-DDPAK; DigiKey ‎LT3081ER#PBF-ND‎
U14: LTC3632; MSOP_MS8E; DigiKey LTC3632EMS8E#PBF-ND‎
U15: LT3092xST; SOT-223-3_TabPin2
V_OUT1: V_out; TestPoint_Pad_D2.0mm

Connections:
5V_lin: 5V1.1, C20.1, C29.1, J3.7, Q3.2 (E), R52.1, R53.2, R55.2, R57.2, R59.2, R61.2, R63.2, R65.2, U5.1 (Vdd), U6.8 (V+), U7.1 (OUT), U8.4 (VSS), U14.2 (VIN)
/LinReg/V_IN_BUCK: U12.6 (IN), U13.6 (IN); also elsewhere on the board
GND: C19.2, C20.2, C21.2, C22.2, C24.1, C25.2, C26.2, C28.2, C30.1, C31.2, C32.2, C33.1, C34.2, C35.2, C36.2, C37.2, C38.2, C39.2, C40.1, D11.2 (A), D12.1 (K), J3.5, J3.6, J3.MP (MountPin), J4.1, L2.2, Q4.1 (B), R27.2, R33.1, R34.1, R39.1, R40.2, R43.2, R44.2, R45.2, R54.1, R56.1, R58.1, R60.1, R62.1, R64.1, R66.1, RV1.1, U5.5 (~LDAC), U5.7 (Vss), U6.4 (V-), U7.2 (GND), U7.3 (GND), U7.6 (GND), U7.7 (GND), U8.8 (VDD/VREF), U9.2 (VCC-); also elsewhere on the board
I_MON: C25.1, R34.2, U6.5 (+), U12.3 (IMON), U13.3 (IMON)
I_Source: C30.2, C31.1, D10.2 (A), J6.1, J6.3, J6.5, R32.1, R67.2, R68.2, RV1.2, RV1.3, U12.2 (SET), U13.2 (SET)
unnamed: -5V1.1, C29.2, C33.2, R41.1, R42.1, R46.1, R51.2, U14.8 (GND), U14.9 (GND)
unnamed: ADC_I1.1, R29.1, U6.6 (-), U6.7
unnamed: ADC_V1.1, R28.1, U6.1, U6.2 (-)
unnamed: C21.1, R29.2, U8.2 (CH0)
unnamed: C22.1, R28.2, U8.3 (CH1)
unnamed: C23.1, R27.1, R30.2, U9.4 (2IN-)
unnamed: C23.2, R31.1, U9.5 (2OUT)
unnamed: C24.2, R26.1, U9.1 (1IN+)
unnamed: C27.1, Q2.2 (E), R33.2, U9.8 (1IN-)
unnamed: C27.2, R36.2, U9.7 (1OUT)
unnamed: C28.1, R38.1, R39.2, U6.3 (+)
unnamed: C32.1, C35.1, C36.1, R47.1, R49.2, U12.4 (OUT), U12.8 (EPAD)
unnamed: C34.1, C37.1, C38.1, R48.1, R50.2, U13.4 (OUT), U13.8 (EPAD)
unnamed: D12.2 (A), R52.2
unnamed: DAC_I1.1, R26.2, U5.8 (VA)
unnamed: DAC_U1.1, R25.2, U5.6 (VB)
unnamed: J3.1, R53.1, R54.2, U5.3 (SCK)
unnamed: J3.2, R55.1, R56.2, U5.4 (SDI)
unnamed: J3.3, R57.1, R58.2, U5.2 (~CS)
unnamed: J3.4, R59.1, R60.2, U8.5 (DIN)
unnamed: J3.8, R65.1, R66.2, U8.1 (~CS~/SHDN)
unnamed: J3.9, R63.1, R64.2, U8.7 (CLK)
unnamed: J3.10, R61.1, R62.2, U8.6 (DOUT)
unnamed: J6.2, R69.2
unnamed: J6.4, R70.2
unnamed: L2.1, U14.1 (SW)
unnamed: Q2.1 (B), R36.1
unnamed: Q2.3 (C), U10.1 (C2), U11.1 (C2)
unnamed: Q3.1 (B), R40.1
unnamed: Q3.3 (C), R41.2, U14.5 (RUN)
unnamed: Q4.2 (E), R51.1
unnamed: R25.1, U9.3 (2IN+)
unnamed: R30.1, R31.2, R32.2
unnamed: R35.2, U10.4 (E2), U11.4 (E2)
unnamed: R37.2, U10.3 (E1), U11.3 (E1)
unnamed: R42.2, U14.3 (ISET)
unnamed: R43.1, TEMP_1.1, U12.5 (TEMP)
unnamed: R44.1, TEMP_2.1, U13.5 (TEMP)
unnamed: R45.1, R46.2, U14.6 (VFB)
unnamed: R47.2, R71.1, U10.2 (C1), U12.1 (ILIM)
unnamed: R48.2, R71.2, R73.1, U11.2 (C1), U13.1 (ILIM)
unnamed: R67.1, U15.2
unnamed: R68.1, R69.1, R70.1, U15.1
unnamed: R72.1, R73.2, RV2.2, RV2.3
VSNK: C19.1, C26.1, C40.2, R35.1, R37.1, U7.8 (IN), U9.6 (VCC+), U15.3; also elsewhere on the board
V_OUTPUT: C39.1, D10.1 (K), D11.1 (K), J5.1, Q4.3 (C), R38.2, R49.1, R50.1, R72.2, RV2.1, V_OUT1.1; also elsewhere on the board

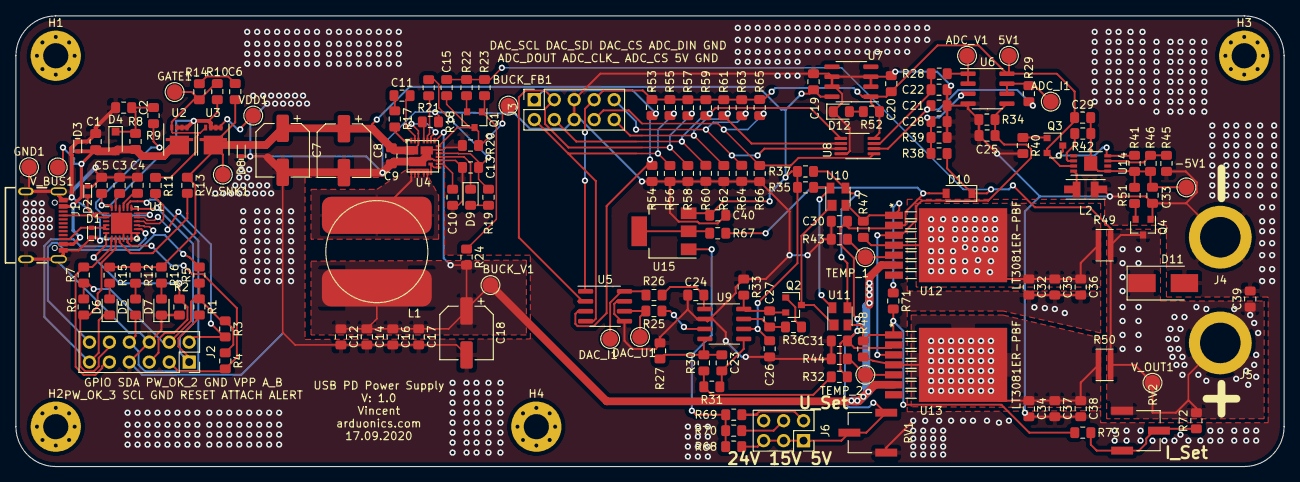
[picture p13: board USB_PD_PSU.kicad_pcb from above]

Board: 2 copper layers, 161.5 x 57.4 mm, 174 parts (0 on the bottom side), 90 nets.

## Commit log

2020-09-18 inital commit
    [BOM.xlsx, Buck_Converter.sch, LinReg.sch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]
2020-09-19 updated schematic and pcb
    [Buck_Converter.sch, LinReg.sch, USB_PD.sch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]
2020-10-07 updated KiCad files, added Ibom
    [LinReg.sch, USB_PD_PSU.kicad_pcb]
2020-10-08 removed outdated BOM
    [BOM.xlsx]

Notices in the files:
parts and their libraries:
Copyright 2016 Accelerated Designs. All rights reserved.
